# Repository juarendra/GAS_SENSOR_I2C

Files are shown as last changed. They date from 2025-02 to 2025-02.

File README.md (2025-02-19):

# GAS_SENSOR_I2C
The Gas Sensor Modular is a highly adaptable gas detection module designed for seamless integration into various applications. Built around the MQ series sensors, this module allows users to replace the gas sensor with any compatible MQ sensor, making it versatile for detecting different gases such as CO, CO₂, NH₃, CH₄, LPG, and more.

This Gas Sensor Modular is an ideal solution for engineers, developers, and researchers looking to implement gas sensing capabilities into their projects efficiently.

## Table of Content

* [Product Specsification](#product-specsification)
* [Technical Spesification](#technical-spesification)
* [Applications](#applications)
* [Advantages](#advantages)
* [Priview Hardware](#priview-hardware)
* [Documentation](#documentation)
  * [Pinout Diagram](#pinout-diagram)
  * [Dimension](#dimension)
  * [BOM](#bom)
  * [Schematic](#schematic0)
  * [Example Program](#examples-program)
* [FAQ](#FAQ)

## Product Specsification
- Interchangeable MQ Series Sensor: Easily swap out the MQ sensor to detect different gases without modifying the PCB.
- I2C Communication Output: Simplifies integration into microcontroller-based systems, reducing the need for multiple analog input pins.
- Built-in Microcontroller: Reads the analog output of the MQ sensor and processes the data.
- Analog-to-Digital Converter (ADC): Converts the analog signal from the MQ sensor into a digital value for precise readings.
- Potentiometer-Adjustable Trigger Threshold: Users can set a specific threshold value, allowing the module to provide a binary digital output based on gas concentration.
- Dual Data Output via I2C:
- Analog Value: Represents the raw sensor reading.
- Digital Value: Indicates whether the gas concentration exceeds the set threshold.

## Technical Spesification

| Features | Value |  
| --- | --- |
| Microcontroller | LGT8F328P |
| Communication | I2C |
| PSU | 5V |

- Sensor Compatibility: MQ series gas sensors (MQ-2, MQ-3, MQ-4, MQ-5, MQ-7, etc.).
- Microcontroller: Integrated for analog signal processing.
- Interface: I2C protocol for easy data communication.
- Power Supply: 5V DC.
- Adjustable Sensitivity: Using an onboard potentiometer.
- Dimensions: Compact and modular for easy integration.

## Applications
- Air quality monitoring
- Industrial gas detection
- Smart home automation
- IoT-based environmental sensing
- Safety and hazard detection systems

# Advantages
- Modular Design – Easily replace MQ sensors for different gas detection needs.
- I2C Communication – Simplifies connection to microcontrollers and embedded systems.
- Dual Output – Provides both analog and digital values for versatile applications.
- User Adjustable Threshold – Allows customization based on required sensitivity levels.

## Preview Hardware
<p align="center">
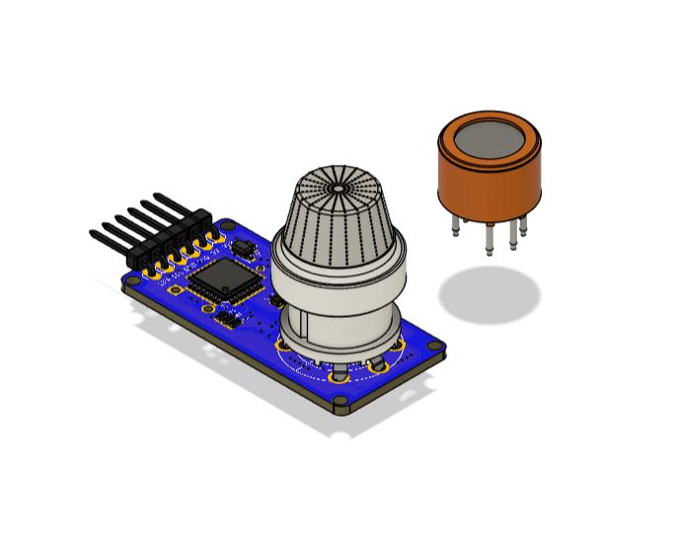
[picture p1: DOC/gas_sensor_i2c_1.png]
  
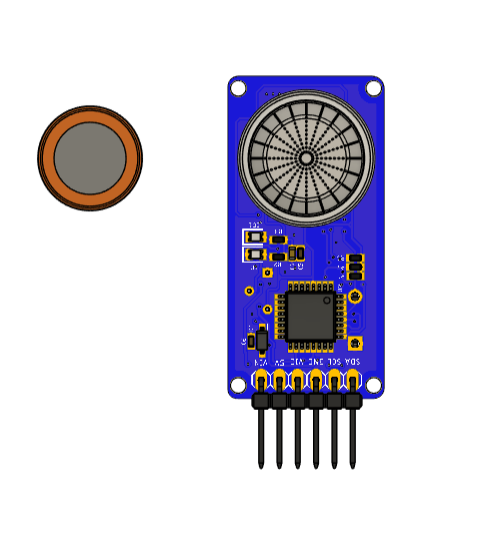
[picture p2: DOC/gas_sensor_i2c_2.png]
  
</p>

## Documentation
### PINOUT

### Dimension
- [Dimension]()
### BOM
- [BOM]()
### Schematic
- Not Available
### Example Program
- [Example Program]()

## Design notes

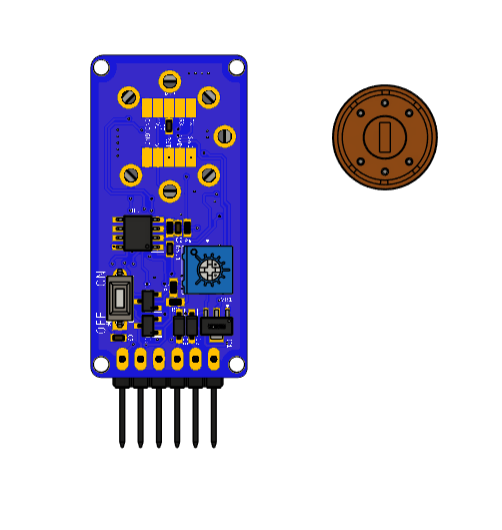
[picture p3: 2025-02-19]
DOC/gas_sensor_i2c_3.png

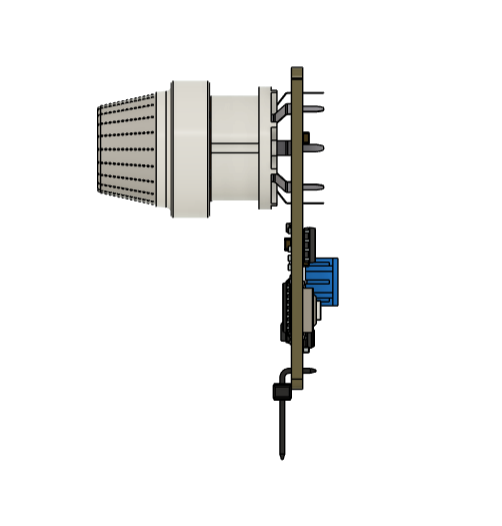
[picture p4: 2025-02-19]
DOC/gas_sensor_i2c_4.png

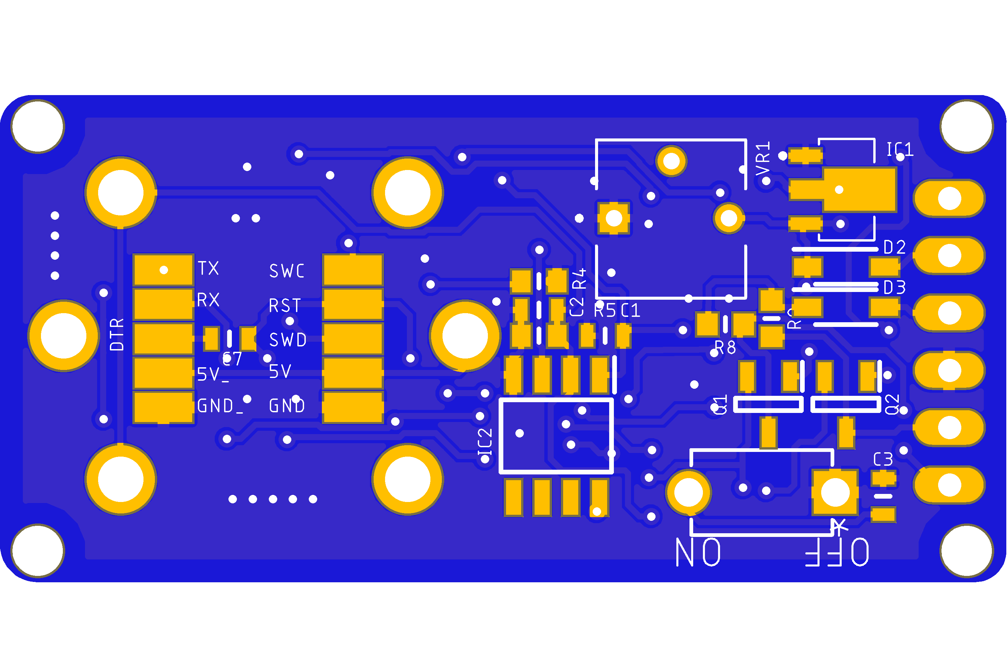
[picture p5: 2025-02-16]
PCB/3D/BOTTOM.png

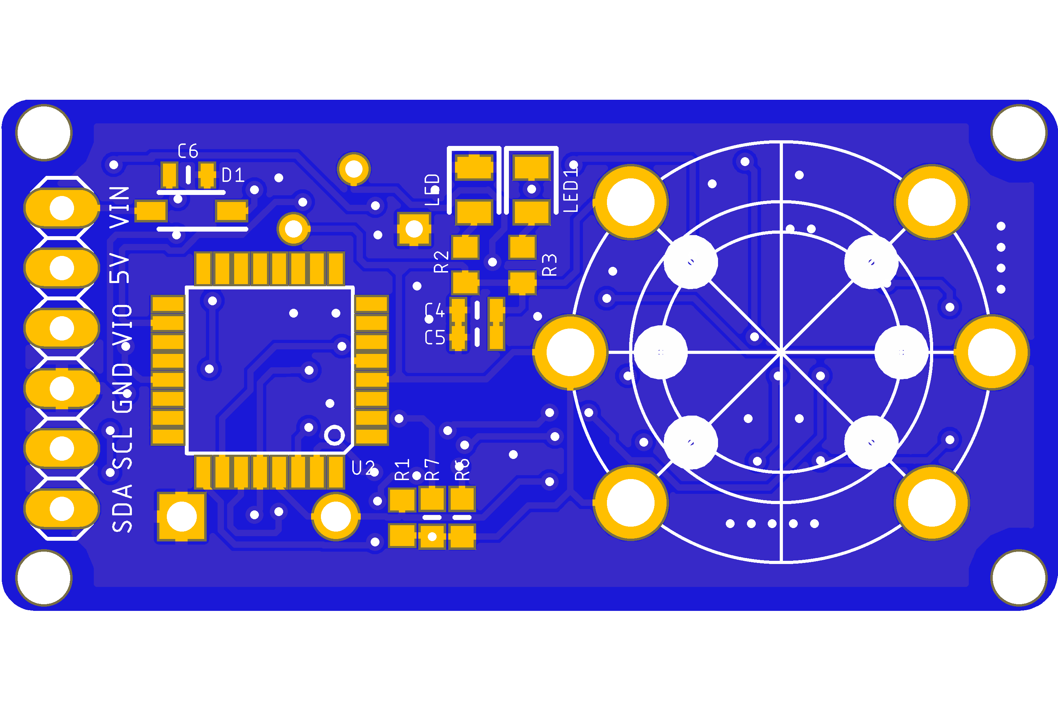
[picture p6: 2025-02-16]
PCB/3D/TOP.png

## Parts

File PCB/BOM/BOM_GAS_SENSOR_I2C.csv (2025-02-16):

Qty | Value | Device | Package | Parts | Description | AVAILABILITY | BUILT_BY | CATEGORY | CHECK_PRICES | COPYRIGHT | DESCRIPTION | HEIGHT | MANUFACTURER_NAME | MANUFACTURER_PART_NUMBER | MF | MOUSER_PART_NUMBER | MOUSER_PRICE-STOCK | MP | PACKAGE | PART_STATUS | POPULARITY | PRICE | SERIES | SNAPEDA_LINK | VALUE | VENDOR
1 |  | MQ-SOCKET | TQFP32-08 | U1 | Check availability
1 |  | PINHD-1X6 | 1X06 | JP1 | PIN HEADER |  |  |  |  |  |  |  |  |  |  |  |  |  |  |  | 79
10 |  | SMD2 | SMD1,27-2,54 | 5V, 5V_, DTR, GND, GND_, RST, RX, SWC, SWD, TX | SMD PAD |  |  |  |  |  |  |  |  |  |  |  |  |  |  |  | 15
7 | 100nf | CGA3E3X7S2A104M080AB | CAPC1608X90N | C1, C2, C3, C4, C5, C6, C7 | Multilayer Ceramic Chip Capacitors, Capacitance=0.1uF, LxWxT:1.6x0.8x0.8mm |  |  |  |  |  | Multilayer Ceramic Chip Capacitors, Capacitance=0.1uF, LxWxT:1.6x0.8x0.8mm | 0.9mm | TDK | CGA3E3X7S2A104M080AB |  | 810-CGA3E3X7S2A104AB | https://www.mouser.co.uk/ProductDetail/TDK/CGA3E3X7S2A104M080AB?qs=6JAMGB%252BEdkwRRFLL6ULUHQ%3D%3D
3 | 10k | CRCW060310K0FKEI | RESC1608X50N | R1, R2, R3 | Standard Thick Film Chip Resistors value 10K0 ohm. |  |  |  |  |  | Standard Thick Film Chip Resistors value 10K0 ohm. | 0.5mm | Vishay | CRCW060310K0FKEI |  | 71-CRCW060310K0FKEI | https://www.mouser.co.uk/ProductDetail/Vishay-Dale/CRCW060310K0FKEI?qs=3qWEzBg5KnKofE%252B8acPBRA%3D%3D
1 | 1825966-1 | 1825966-1 | SWDIP2_256X170P100 | RESET |  |  | EMA_UL_Team | Tactile Switches |  | Copyright (C) 2016 Accelerated Designs. All rights reserved | FSMCH=3.5 X 6.0 X 4.3 TACT SWITCH, HT |  |  | 1825966-1 |  |  |  |  |  | active |  |  | Unknown |  |  | TE Connectivity
3 | 1N5819HW-7-F | 1N5819HW-7-F | SOD3716X145N | D1, D2, D3 | Diode Schottky 1A 40V SOD123 Diodes Inc 1N5819HW-7-F, SMT Schottky Diode, 40V 1A, 2-Pin SOD-123 |  |  |  |  |  | Diode Schottky 1A 40V SOD123 Diodes Inc 1N5819HW-7-F, SMT Schottky Diode, 40V 1A, 2-Pin SOD-123 | 1.45mm | Diodes Incorporated | 1N5819HW-7-F |  | 621-1N5819HW-F | https://www.mouser.co.uk/ProductDetail/Diodes-Incorporated/1N5819HW-7-F?qs=NQ47qNm99eDyWTEd07miYA%3D%3D
4 | 2.2k | CR0603-FX-2201ELF | RESC1608X55N | R6, R7, R8, R9 | BOURNS - CR0603-FX-2201ELF - RES, THICK FILM, 2K2, 1%, 0.1W, 0603 |  |  |  |  |  | BOURNS - CR0603-FX-2201ELF - RES, THICK FILM, 2K2, 1%, 0.1W, 0603 | 0.55mm | Bourns | CR0603-FX-2201ELF |  | 652-CR0603FX-2201ELF | https://www.mouser.co.uk/ProductDetail/Bourns/CR0603-FX-2201ELF?qs=zx2075yZkZKUzLkJq4yLqg%3D%3D
2 | 2N7002 | 2N7002 | SOT95P280X125-3N | Q1, Q2 | This Power MOSFET is the second generation of STMicroelectronics unique single feature size strip-based process. The resulting transistor shows extremely high packing density for low onresistance, rugged avalanche characteristics and less critical alignment steps therefore a remarkable manufacturing reproducibility. |  |  |  |  |  | This Power MOSFET is the second generation of STMicroelectronics unique single feature size strip-based process. The resulting transistor shows extremely high packing density for low onresistance, rugged avalanche characteristics and less critical alignment steps therefore a remarkable manufacturing reproducibility. | 1.25mm | STMicroelectronics | 2N7002 |  | 511-2N7002 | https://www.mouser.co.uk/ProductDetail/STMicroelectronics/2N7002?qs=gr8Zi5OG3MhbM22ee9cxCw%3D%3D
1 | 3362P-1-253LF | 3362P-1-253LF | TRIM_3362P-1-253LF | VR1 | Check availability | In Stock |  |  | https://www.snapeda.com/parts/3362P-1-253LF/Bourns/view-part/?ref=eda |  | 1/4 Sq, Thru-Hole, TRIMMER, 25 Kilohms, Cermet, Single Turn | Bourns 3362P-1-253LF |  |  |  | Bourns |  |  | 3362P-1-253LF | 3362P-1 Bourns Inc. |  |  | None |  | https://www.snapeda.com/parts/3362P-1-253LF/Bourns/view-part/?ref=snap
1 | 47k | AC0603FR-7W47KL | RESC1608X55N | R5 | AEC-Q200 qualified Moisture sensitivity level: MSL 1 AC series soldering is compliant with J-STD-020D Halogen free epoxy |  |  |  |  |  | AEC-Q200 qualified Moisture sensitivity level: MSL 1 AC series soldering is compliant with J-STD-020D Halogen free epoxy | 0.55mm | YAGEO | AC0603FR-7W47KL
1 | 5.1r | RT0603DRE075R1L | RESC1608X55N | R4 | Thin Film Resistors - SMD 1/10W 5.1 ohm .5% 50ppm |  |  |  |  |  | Thin Film Resistors - SMD 1/10W 5.1 ohm .5% 50ppm | 0.55mm | YAGEO | RT0603DRE075R1L
1 | AZ1117CR2-5.0TRG1 | AZ1117CR2-5.0TRG1 | AP738133Y13 | IC1 | Linear Voltage Regulator IC Positive Fixed 1 Output 1A SOT-89-3 |  |  |  |  |  | Linear Voltage Regulator IC Positive Fixed 1 Output 1A SOT-89-3 | 1.6mm | Diodes Incorporated | AZ1117CR2-5.0TRG1 |  | 621-AZ1117CR25.0TRG1 | https://www.mouser.co.uk/ProductDetail/Diodes-Incorporated/AZ1117CR2-5.0TRG1?qs=lqAf%2FiVYw9jcPQErqCnZAA%3D%3D
2 | Green | 150080BS75000 | LEDC2012X80N | LED, LED1 | LED,Wurth Elektronik,150080BS75000 Wurth Elektronik 150080BS75000, WL-SMCW Series Blue LED, 470 nm 2012 (0805) Clear, Rectangle Lens SMD package |  |  |  |  |  | LED,Wurth Elektronik,150080BS75000 Wurth Elektronik 150080BS75000, WL-SMCW Series Blue LED, 470 nm 2012 (0805) Clear, Rectangle Lens SMD package | 0.8mm | Wurth Elektronik | 150080BS75000 |  | 710-150080BS75000 | https://www.mouser.co.uk/ProductDetail/Wurth-Elektronik/150080BS75000?qs=2kOmHSv6VfT2tBo3UPVqAQ%3D%3D |  |  |  |  |  |  |  | Green
1 | LGT8F328P | LGT8F328P | TQFP32-08 | U2 | Check availability | Not in stock |  |  | https://www.snapeda.com/parts/LGT8F328P/Arduino/view-part/?ref=eda |  |  |  |  |  | Arduino |  |  | LGT8F328P | Package |  |  | None |  | https://www.snapeda.com/parts/LGT8F328P/Arduino/view-part/?ref=snap
1 | LM393D | LM393D | SOIC127P600X175-8N | IC2 | LM393D, Dual Comparator Open Collector 1.3us 12 V, 15 V, 18 V, 24 V, 28 V, 3 V, 5 V, 9 V 8-Pin SO |  |  |  |  |  | LM393D, Dual Comparator Open Collector 1.3us 12 V, 15 V, 18 V, 24 V, 28 V, 3 V, 5 V, 9 V 8-Pin SO | 1.75mm | STMicroelectronics | LM393D |  | 511-LM393D | https://www.mouser.co.uk/ProductDetail/STMicroelectronics/LM393D?qs=htKRmzjvioSpfPyLiLnV1A%3D%3D

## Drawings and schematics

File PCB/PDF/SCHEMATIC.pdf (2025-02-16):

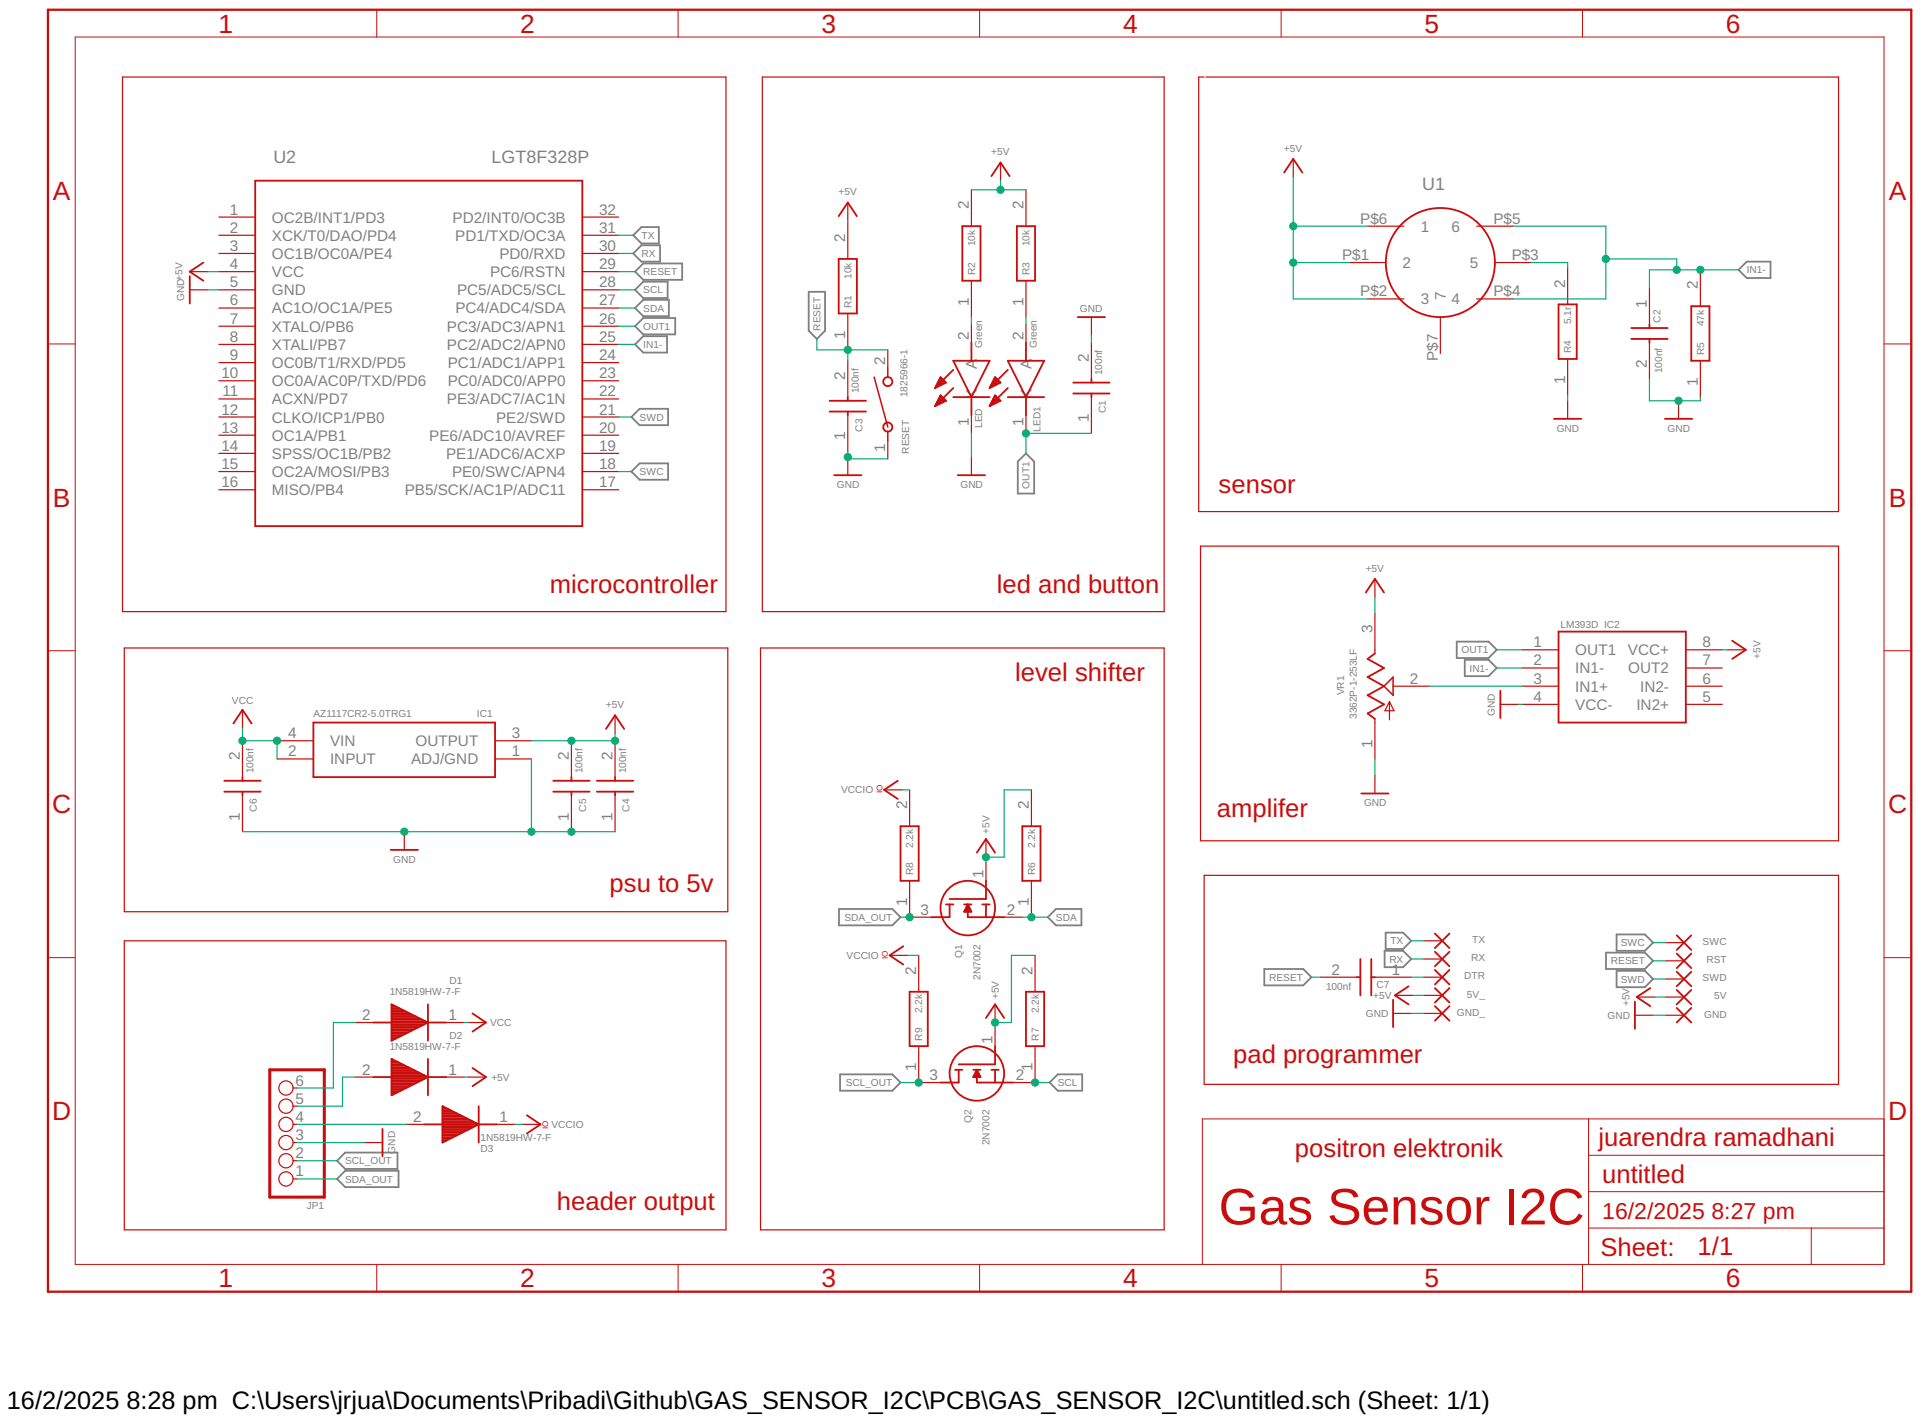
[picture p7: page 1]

16/2/2025 8:28 pm C:\Users\jrjua\Documents\Pribadi\Github\GAS_SENSOR_I2C\PCB\GAS_SENSOR_I2C\untitled.sch (Sheet: 1/1)

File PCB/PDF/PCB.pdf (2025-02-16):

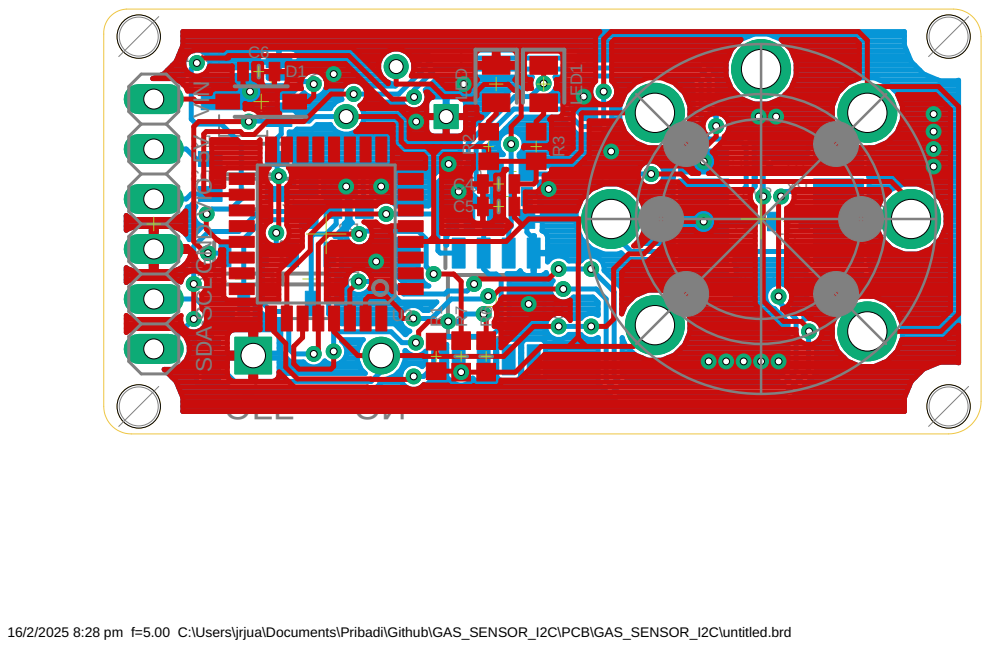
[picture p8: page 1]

16/2/2025 8:28 pm f=5.00 C:\Users\jrjua\Documents\Pribadi\Github\GAS_SENSOR_I2C\PCB\GAS_SENSOR_I2C\untitled.brd

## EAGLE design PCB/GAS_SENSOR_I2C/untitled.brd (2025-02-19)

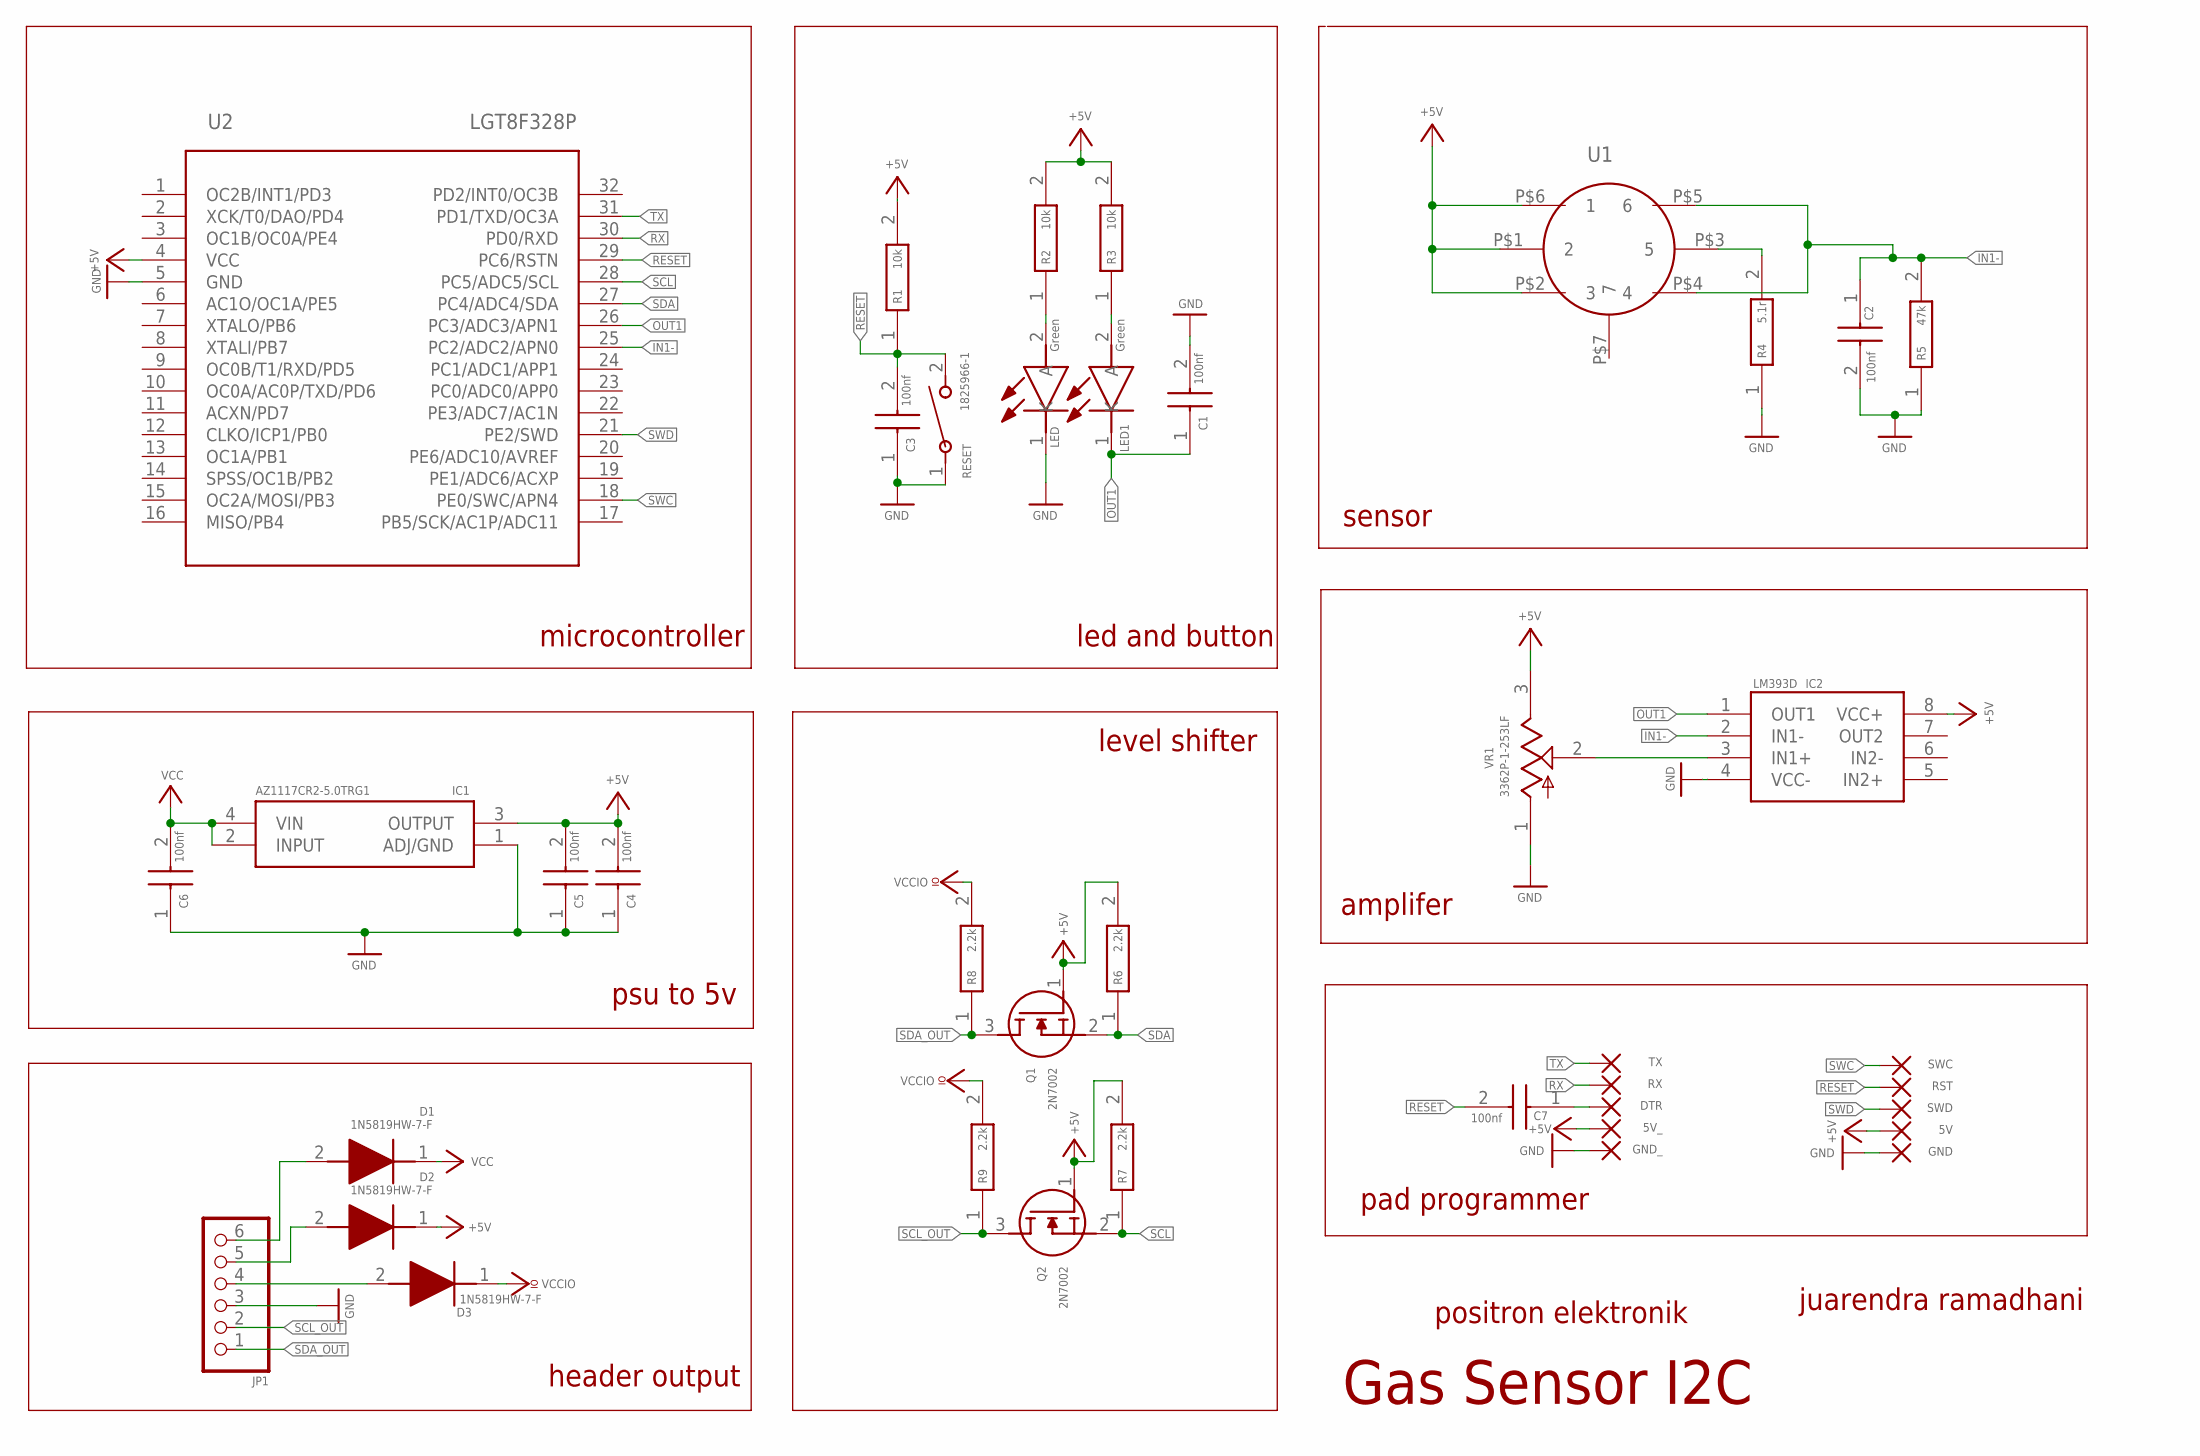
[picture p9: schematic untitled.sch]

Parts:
5V, 5V_: SMD2; SMD1,27-2,54
C1, C2, C3, C4, C5, C6, C7: 100nf; CAPC1608X90N
D1, D2, D3: 1N5819HW-7-F; SOD3716X145N
DTR: SMD2; SMD1,27-2,54
GND: SMD2; SMD1,27-2,54
GND_: SMD2; SMD1,27-2,54
IC1: AZ1117CR2-5.0TRG1; AP738133Y13
IC2: LM393D; SOIC127P600X175-8N
JP1: PINHD-1X6; 1X06
LED, LED1: Green; LEDC2012X80N
Q1, Q2: 2N7002; SOT95P280X125-3N
R1, R2, R3: 10k; RESC1608X50N
R4: 5.1r; RESC1608X55N
R5: 47k; RESC1608X55N
R6, R7, R8, R9: 2.2k; RESC1608X55N
RESET: 1825966-1; SWDIP2_256X170P100
RST: SMD2; SMD1,27-2,54
RX: SMD2; SMD1,27-2,54
SWC: SMD2; SMD1,27-2,54
SWD: SMD2; SMD1,27-2,54
TX: SMD2; SMD1,27-2,54
U1: MQ-SOCKET; TQFP32-08
U2: LGT8F328P; TQFP32-08
VR1: 3362P-1-253LF; TRIM_3362P-1-253LF

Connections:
+5V: 5V.1, 5V_.1, C4.2, C5.2, D2.1 (K), IC1.3 (OUTPUT), IC2.8 (VCC+), Q1.1 (G), Q2.1 (G), R1.2, R2.2, R3.2, R6.2, R7.2, U1.P$1 (2), U1.P$2 (3), U1.P$6 (1), U2.4 (VCC), VR1.3 (CW)
GND: C1.2, C2.2, C3.1, C4.1, C5.1, C6.1, GND.1, GND_.1, IC1.1 (ADJ/GND), IC2.4 (VCC-), JP1.3, LED.1 (K), R4.1, R5.1, RESET.1, U2.5 (GND), VR1.1 (CCW)
IN1-: C2.1, IC2.2 (IN1-), R5.2, U1.P$4 (4), U1.P$5 (6), U2.25 (PC2/ADC2/APN0)
unnamed: LED.2 (A), R2.1
unnamed: LED1.2 (A), R3.1
unnamed: R4.2, U1.P$3 (5)
unnamed: D1.2 (A), JP1.6
unnamed: D3.2 (A), JP1.4
unnamed: IC2.3 (IN1+), VR1.2 (WIPER)
unnamed: D2.2 (A), JP1.5
unnamed: C7.1, DTR.1
OUT1: C1.1, IC2.1 (OUT1), LED1.1 (K), U2.26 (PC3/ADC3/APN1)
RESET: C3.2, C7.2, R1.1, RESET.2, RST.1, U2.29 (PC6/RSTN)
RX: RX.1, U2.30 (PD0/RXD)
SCL: Q2.2 (S), R7.1, U2.28 (PC5/ADC5/SCL)
SCL_OUT: JP1.2, Q2.3 (D), R9.1
SDA: Q1.2 (S), R6.1, U2.27 (PC4/ADC4/SDA)
SDA_OUT: JP1.1, Q1.3 (D), R8.1
SWC: SWC.1, U2.18 (PE0/SWC/APN4)
SWD: SWD.1, U2.21 (PE2/SWD)
TX: TX.1, U2.31 (PD1/TXD/OC3A)
VCC: C6.2, D1.1 (K), IC1.2 (INPUT), IC1.4 (VIN)
VCCIO: D3.1 (K), R8.2, R9.2

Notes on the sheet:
positron elektronik
juarendra ramadhani
Gas Sensor I2C
level shifter
led and button
sensor
amplifer
pad programmer
header output
psu to 5v
microcontroller

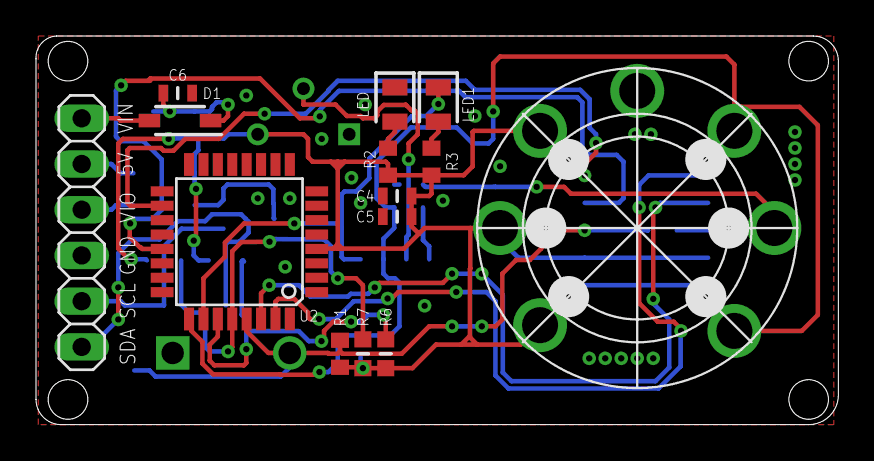
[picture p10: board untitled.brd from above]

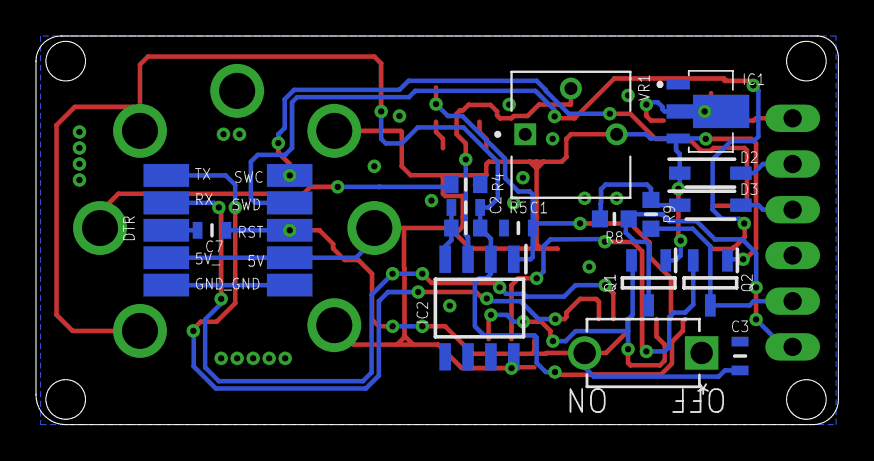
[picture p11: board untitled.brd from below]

Board: 2 copper layers, 44.6 x 21.6 mm, 40 parts (26 on the bottom side), 23 nets.

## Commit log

2025-02-16 FEAT: update mq socket footprint
    [untitled.brd, untitled.sch]
2025-02-19 FEAT: add image and 3d model
    [untitled.brd, untitled.sch]

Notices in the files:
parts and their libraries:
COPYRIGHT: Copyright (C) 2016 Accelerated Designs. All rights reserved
